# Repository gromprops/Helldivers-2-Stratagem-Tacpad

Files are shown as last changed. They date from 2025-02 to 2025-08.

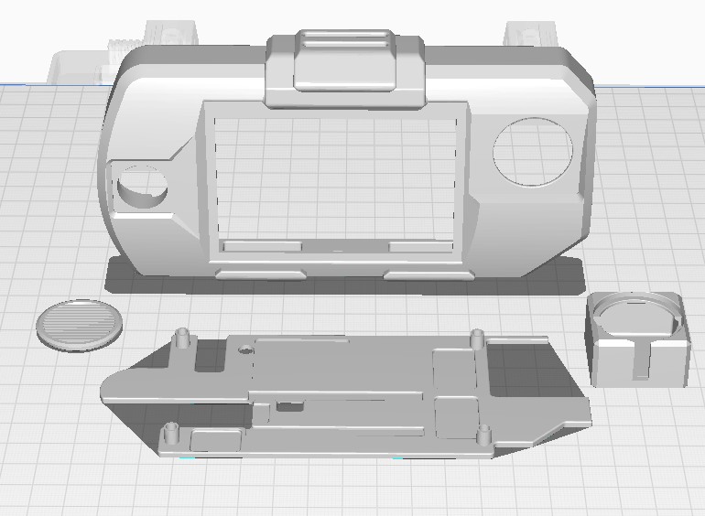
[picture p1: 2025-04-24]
STL/STL Orientation.jpg

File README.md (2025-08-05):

---

---

<h1 id="helldivers-2-stratagem-tacpad">Helldivers 2 Stratagem Tacpad</h1>
<h2 id="introduction">Introduction</h2>
<p>Welcome to the Stratagem Tacpad Readme! This interactive cosplay prop is inspired by the Helldivers games. It simulates the in-game process of calling in support Stratagems with arrow-key commands. This readme will guide you through operation and troubleshooting.</p>
<p><strong>Please Note:</strong></p>
<ul>
<li>This device is a fan-made replica and is not official Helldivers merchandise.</li>
<li>Read through all instructions before operation.</li>
<li>See the <a href="https://github.com/gromprops/Helldivers-2-Stratagem-Tacpad/blob/main/Disassembly-Reassembly.md">Assembly/Disassembly Guide</a> for instructions for proper disassembly/reassembly. This will be necessary to paint the housing.</li>
</ul>
<p><strong>Table of Contents</strong></p>
<ol>
<li>Safety &amp; Care Instructions</li>
<li>Features and Operation</li>
<li>Maintenance &amp; Troubleshooting</li>
<li>Support</li>
</ol>
<p><strong>Safety &amp; Care Instructions</strong></p>
<ul>
<li>Keep the Tacpad dry and away from extreme heat.</li>
<li>Avoid dropping the device, as it may damage internal electronics.</li>
<li>Avoid charging the device for more than 24 hours at a time, as this can potentially degrade the battery life.</li>
</ul>
<p><strong>Power and Charging</strong><br>
The Tacpad includes a built-in battery and micro-USB charging port. Charge it fully before use. The charging indicator LED shown below will turn on when USB power is detected.</p>
<p>Use the power switch shown below to power on the Tacpad.</p>
<p>Tacpad Rear View</p>
<h2 id="features--operation">Features &amp; Operation</h2>
<p><strong>Primary Operation</strong><br>
The touchscreen interface provides arrow keys for entering Stratagem sequences. When the entered sequence matches an equipped Stratagem, the Tacpad will signal activation.</p>
<ul>
<li>Press the silver Stratagem button to activate the on-screen arrows.</li>
<li>Tap the on-screen arrows in the correct sequence.</li>
<li>Once a matching sequence is entered, the appropriate Stratagem will highlight on the screen and the button LED will start flashing.</li>
<li>Press the Stratagem button again to de-activate the active Stratagem.</li>
</ul>
<p>Tacpad Main Operation Mode</p>
<p><strong>Stratagem Loadout Selection</strong><br>
The Tacpad allows you to select and store up to 4 equipped Stratagems at startup. You can also enable a setting to randomize your loadout each time the device boots.</p>
<ul>
<li>To equip Stratagems, press the LOADOUT button to open the loadout menu.</li>
<li>Select the desired Stratagems and once four Stratagems are selected, the CONFIRM button will activate, allowing you to save your loadout.</li>
<li>Pressing the EXIT button will discard any selected Stratagems and return to the main screen.</li>
<li>Enable Random Loadout mode by toggling the setting in the configuration menu.<br>
Tacpad Loadout Mode</li>
</ul>
<p><strong>Settings Mode</strong><br>
To access Tacpad settings, press the gear button in the menu bar. The current firmware version is displayed at the top of the Settings menu</p>
<ul>
<li><strong>Volume:</strong> Use the +/- buttons to adjust the volume.</li>
<li><strong>Stratagem Randomization:</strong> Toggle on to load random Stratagems on every boot-up.</li>
<li><strong>Stratagem Ball:</strong> Toggle on to enable use of the wireless Stratagem Ball companion device.</li>
<ul>
<li><strong>Pair Button:</strong> Starts pairing mode</li>
<li><strong>Ch:</strong> Shows the currently paired channel ID.</li>
</ul>
<li><strong>Random Player:</strong> Toggle on to generate a random Player Tag and Super Destroyer name on every boot-up. If toggled off, a custom Player Tag and Super Destroyer name is selectable:</li>
<ul>
<li><strong>Player Tag:</strong> Previews the currently stored Player Tag. Pressing the “&gt;” button will open the Player Tag Selection menu.</li>
<li><strong>Super Destroyer:</strong> Previews the currently stored Super Destroyer name. Pressing the ">" buttons will open the Super Destroyer Prefix and Suffix Selection menus respectively.</li>
</ul>
</ul>
<p><strong>Software Updates</strong><br>
All updates are free and simple to install. New firmware updates will be made available from the Github repository.</p>
<ul>
<li>Check your current firmware version by looking at the top of the Settings menu.</li>
<li>Download the newest firmware (.uf2 file) release from <a href="https://github.com/gromprops/Helldivers-2-Stratagem-Tacpad/releases">here</a.</li>
<li>Connect the Tacpad to a computer via the supplied USB cable.</li>
<li>Press and hold the reset button on the back next to the USB plug while switching on the Tacpad.</li>
<li>A USB storage device called RP2350 should appear on the connected computer.</li>
<li>Drag the .uf2 file into the USB storage device. Once the transfer is complete, the Tacpad will automatically boot with the new firmware.</li>
</ul>

<h3 id="wireless-module-installation">Wireless Module Installation</h3>
<p>A wireless module is required for use of the Wireless Stratagem Ball companion device. Follow these instructions for proper installation.</p>
<ul>
<li>Power down the Tacpad and open the back casing by unscrewing the four screws.</li>
<li>Locate the wireless module slot and 4-pin connector socket shown below:</li>
<p>Wireless module expansion connector</p>
<li>Position the wireless module into its slot with the antenna facing  <i>up</i>. The left edge of the module should slide into a small notch in the wall of the Tacpad housing.</li>
<p>Properly installed wireless module</p>
<li>Plug the module cable into the socket.</li>
<li>Reinstall the back casing.</li>
<li>Ensure that the Tacpad firmware is updated to at least v1.2.</li>
<li>Enable the <strong>Stratagem Ball</strong> setting and pair with a Stratagem Ball.</li>
</ul>

<h2 id="maintenance--troubleshooting">Maintenance &amp; Troubleshooting</h2>
<ul>
<li><strong>Cleaning:</strong> Gently wipe the Tacpad’s exterior with a soft, dry cloth.</li>
<li><strong>Storage:</strong> Charge the Tacpad before storing for extended periods of time. This helps preserve battery life.</li>
<li><strong>Firmware Updates:</strong> Future software updates can be applied by connecting the Tacpad to your computer and dragging the update file into the device’s storage.</li>
</ul>
<p><strong>Support</strong><br>
Stay tuned for additional features. Follow the official <a href="https://www.instagram.com/gromlonprops/">Gromlon Props Instagram</a> for notifications of new updates and projects.</p>
<p>For any questions or support inquiries, please reach out through <a href="https://www.etsy.com/shop/GromlonProps">Etsy</a> messaging.</p>
<blockquote>
<p>Written with <a href="https://stackedit.io/">StackEdit</a>.</p>
</blockquote>

<!--stackedit_data:
eyJoaXN0b3J5IjpbNDEzODk0Mzg2LDMyMDE2NTQ0Niw2NDM3OD
U0NDcsLTg0Mzc0OTYwNiwtMTg4OTAyMDE3NiwxNDMxNjc4MjJd
fQ==
-->

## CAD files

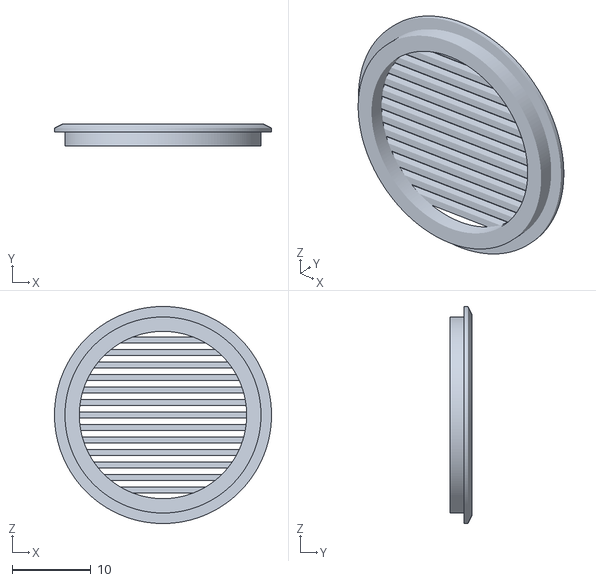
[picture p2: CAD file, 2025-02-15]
STL/HD2 - Tacpad - Speaker Cover v1.1.stl
27.5 x 2.75 x 27.5

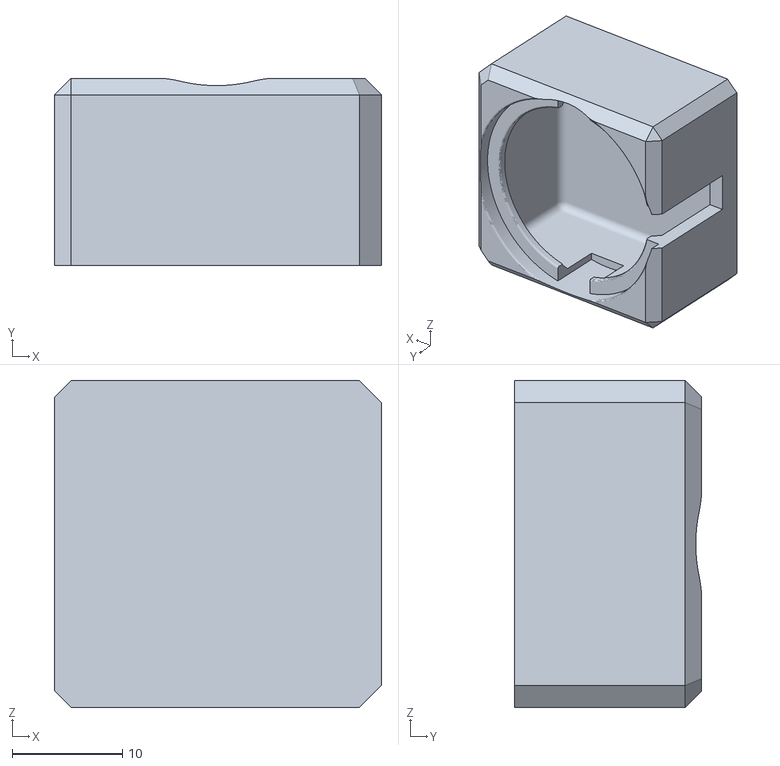
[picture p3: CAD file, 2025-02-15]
STL/HD2 - Tacpad - Speaker Housing v1.stl
29.7 x 17.0 x 29.7

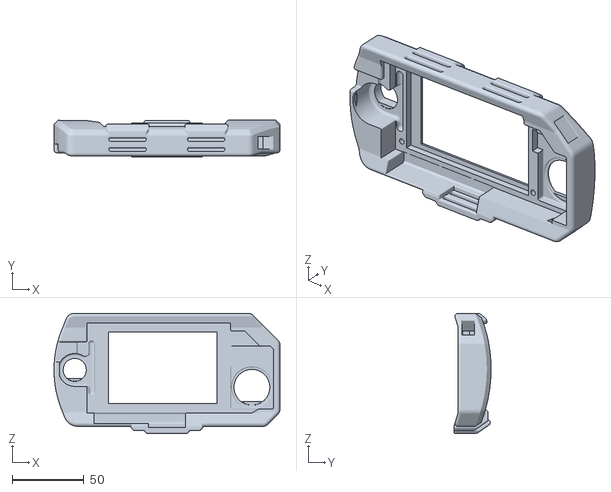
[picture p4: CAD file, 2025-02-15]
STL/HD2 - Tacpad - Body v1.2.stl
158.0 x 26.0 x 84.0

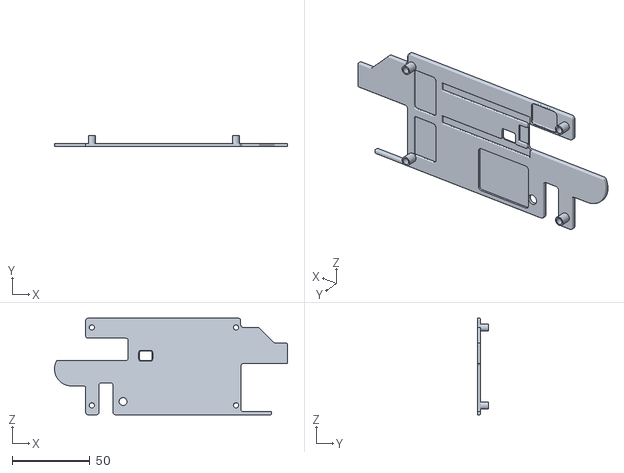
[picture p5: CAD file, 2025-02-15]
STL/HD2 - Tacpad - Backplate v 1.1.stl
149.5 x 7.00 x 62.0

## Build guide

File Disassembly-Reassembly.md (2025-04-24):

---

---

<h1 id="stratagem-tacpad-disassembly-and-reassembly-guide">Stratagem Tacpad Disassembly and Reassembly Guide</h1>
<p>This guide explains how to disassemble and reassemble the Stratagem Tacpad for painting or maintenance. Follow each step carefully to avoid damaging the device. For visual reference, please refer to the image below and accompanying reassembly video.</p>
<p><strong>Included Parts</strong><br>
Parts with associated plug lables</p>
<hr>
<h2 id="disassembly-instructions"><strong>Disassembly Instructions</strong></h2>
<ol>
<li>
<p><strong>Power Down</strong></p>
<ul>
<li>Ensure the Tacpad is turned off.</li>
<li>Place it face down on a soft cloth to prevent scratching.</li>
</ul>
</li>
<li>
<p><strong>Remove Backplate</strong></p>
<ul>
<li>Use the provided 1.5mm hex key to unscrew the 4 screws securing the backplate. Set screws aside safely.</li>
</ul>
</li>
<li>
<p><strong>Disconnect Cables</strong></p>
<ul>
<li>Carefully unplug the 4 cables connected to the main board.</li>
<li>For the battery cable, take special care to avoid shorting the contacts with any metal object.</li>
</ul>
</li>
<li>
<p><strong>Remove Battery</strong></p>
<ul>
<li>Gently lift the battery out of its slot and set aside.</li>
</ul>
</li>
<li>
<p><strong>Remove Main Board and Screen</strong></p>
<ul>
<li>Slowly pull the main board and screen assembly out of the casing.</li>
<li>If it resists, use a clean, soft cloth to gently push the screen from the front to dislodge the assembly. <strong>Do not use sharp or hard objects.</strong></li>
</ul>
</li>
<li>
<p><strong>Remove Speaker Housing</strong></p>
<ul>
<li>Gently pry the speaker housing loose by pushing on the top near the cable.</li>
</ul>
</li>
<li>
<p><strong>Remove Power Switch</strong></p>
<ul>
<li>Use a small, long object to push on the back of the power switch and remove it.</li>
</ul>
</li>
<li>
<p><strong>Remove Stratagem Switch</strong></p>
<ul>
<li>Unscrew the flat nut from the back of the stratagem switch.</li>
<li>Push the switch out from the back to remove.</li>
</ul>
</li>
<li>
<p><strong>Remove Speaker Cover (Initial Disassembly Only)</strong></p>
<ul>
<li>Gently push the speaker cover out from the back of the casing.</li>
</ul>
</li>
</ol>
<p>At this point, the Tacpad is fully disassembled and ready for sanding, priming, and painting.</p>
<h2 id="reassembly-instructions"><strong>Reassembly Instructions</strong></h2>
<p><strong>Reassembly Video</strong><br>
<a href="https://www.youtube.com/watch?v=AuhXsXbZYts">Tacpad Reassembly Video</a></p>
<ol>
<li>
<p><strong>Reattach Speaker Cover</strong></p>
<ul>
<li>Apply a small amount of glue to the inside rim of the speaker cover.</li>
<li>Position the slots horizontally and press the cover into the case until the outer rim is flush with the face of the casing.</li>
</ul>
</li>
<li>
<p><strong>Reinstall Stratagem Switch</strong></p>
<ul>
<li>Thread the cable plug through the flat nut and tighten the nut onto the back of the switch. Hand-tighten only.</li>
<li>Insert the switch into the front of the casing cable-first, and align the flange flush with the case face. Rotate the switch so the cable points toward the bottom cable recess.</li>
</ul>
</li>
<li>
<p><strong>Reinstall Power Switch</strong></p>
<ul>
<li>Insert the power switch into its slot with the “ON” side (I) facing the top of the casing.</li>
<li>Press until the switch snaps into place.</li>
</ul>
</li>
<li>
<p><strong>Install Main Board Assembly</strong></p>
<ul>
<li>Place the main board assembly into the casing.</li>
<li>Gently push on the corners until the assembly is fully seated, with no visible gap between the screen and casing border from the front. <strong>Do not push on the casing border, as it may crack.</strong></li>
</ul>
</li>
<li>
<p><strong>Reinsert Speaker Housing</strong></p>
<ul>
<li>Press the speaker housing into the top-left corner of the casing, ensuring the cable exits at the top.</li>
<li>The back of the housing should sit flush with the casing edge.</li>
</ul>
</li>
<li>
<p><strong>Reconnect Cables</strong></p>
<ul>
<li>Verify the power switch is OFF (O).</li>
<li>Connect the cables according to their labels on the main board:
<ul>
<li><strong>BATT</strong>: Battery</li>
<li><strong>SPK</strong>: Speaker</li>
<li><strong>PWR-SW</strong>: Power switch</li>
<li><strong>ST-SW</strong>: Stratagem switch (ensure cable routes through slot below the switch cutout).</li>
</ul>
</li>
</ul>
</li>
<li>
<p><strong>Replace Battery</strong></p>
<ul>
<li>Seat the battery into its designated slot above the main board assembly.</li>
</ul>
</li>
<li>
<p><strong>Reinstall Backplate</strong></p>
<ul>
<li>Align the backplate and adjust any cables to ensure the screw mounts contact the main board assembly.</li>
<li>Tighten the 4 screws gently until the backplate is flush with the casing edges. <strong>Do not overtighten to avoid cracking the casing.</strong></li>
</ul>
</li>
</ol>
<hr>
<p>Your Stratagem Tacpad is now reassembled and ready for use. For further assistance, refer to the video or contact support via Etsy. Enjoy bringing your painted and customized Tacpad to life!</p>
<blockquote>
<p>Written with <a href="https://stackedit.io/">StackEdit</a>.</p>
</blockquote>

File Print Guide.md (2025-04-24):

---

---

<h1 id="stratagem-tacpad-housing-printing-guide">Stratagem Tacpad Housing Printing Guide</h1>
<p>This guide provides an overview of printed parts and recommendations for 3d printing the components.</p>
<hr>
<h2 id="printed-parts"><strong>Printed Parts</strong></h2>
<p><a href="https://github.com/gromprops/Helldivers-2-Stratagem-Tacpad/blob/main/STL/HD2%20-%20Tacpad%20-%20Body%20v1.2.stl" title="HD2 - Tacpad - Body v1.2.stl">HD2 - Tacpad - Body v1.2.stl</a><br>
<a href="https://github.com/gromprops/Helldivers-2-Stratagem-Tacpad/blob/main/STL/HD2%20-%20Tacpad%20-%20Backplate%20v%201.1.stl" title="HD2 - Tacpad - Backplate v 1.1.stl">HD2 - Tacpad - Backplate v 1.1.stl</a><br>
<a href="https://github.com/gromprops/Helldivers-2-Stratagem-Tacpad/blob/main/STL/HD2%20-%20Tacpad%20-%20Speaker%20Housing%20v1.stl" title="HD2 - Tacpad - Speaker Housing v1.stl">HD2 - Tacpad - Speaker Housing v1.stl</a><br>
<a href="https://github.com/gromprops/Helldivers-2-Stratagem-Tacpad/blob/main/STL/HD2%20-%20Tacpad%20-%20Speaker%20Cover%20v1.1.stl" title="HD2 - Tacpad - Speaker Cover v1.1.stl">HD2 - Tacpad - Speaker Cover v1.1.stl</a></p>
<h2 id="recommended-print-orientation"><strong>Recommended Print Orientation</strong></h2>
<p>Recommended STL orientation</p>
<h2 id="print-settings"><strong>Print Settings</strong></h2>
<p><strong>Body:</strong></p>
<ul>
<li>Layer Height: 0.12 - 0.2</li>
<li>Infill: 20%</li>
<li>Walls: 4</li>
<li>Top/Bottom Layers: 5</li>
<li>Support: ON</li>
</ul>
<p><strong>Backplate/Speaker Housing:</strong></p>
<ul>
<li>Layer Height: 0.2 - 0.28</li>
<li>Infill: 10%</li>
<li>Walls: 3</li>
<li>Top/Bottom Layers: 3</li>
<li>Support: OFF</li>
</ul>
<p><strong>Speaker Cover:</strong></p>
<ul>
<li>Layer Height: 0.12</li>
<li>Infill: 10%</li>
<li>Walls: 3</li>
<li>Top/Bottom Layers: 3</li>
<li>Support: ON</li>
</ul>
<blockquote>
<p>Written with <a href="https://stackedit.io/">StackEdit</a>.</p>
</blockquote>

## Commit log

2025-02-15 Add housing STL for self-print kit
    [HD2 - Tacpad - Backplate v 1.1.stl, HD2 - Tacpad - Body v1.2.stl, HD2 - Tacpad - Speaker Cover v1.1.stl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]
2025-02-19 Print Guide.md created from https://stackedit.io/
2025-02-20 Print Guide.md updated from https://stackedit.io/
2025-08-05 Improve speaker housing retention
    The backplate and speaker housing STLs were updated with a retention notch to prevent the speaker housing from sliding out when the backplate is installed.
2025-08-05 Update SFX batch script
    mp3copy.bat was updated to accept sd cards as low as 64MB capacity. Some Tacpads were shipped with smaller SD cards that were being rejected by the previous 128MB lower limit.
